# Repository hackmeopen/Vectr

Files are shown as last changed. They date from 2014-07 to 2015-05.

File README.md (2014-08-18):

Vectr
=====

Vectr 3D Sensing Controller

Vectr is an open source 3D sensing controller and sequencer. The board files and firmware are here. Vectr software and hardware are released under 
the Modified BSD License. Vectr uses a number of libraries from Microchip which, although they are free to use,are not fully open source. 
The BSD license allows me to release my contributions as free to use while retaining Microchip's copyrights. This arrangement
was worked out in discussions with the legal department of Microchip.

You are free to use Vectr's firmware and hardware for your own purposes.

Vectr uses Microchip Technology's MGC3130 to sense a user's hand in free space above it's surface. It is able to determine the position of the user's hand within a  cubic volume which is 4inx4inx6in. 

Vectr has 36 LEDs which provide visual feedback about where it senses the user's hand.

It is designed to work with Eurorack modular synthesizers, but the underlying technology can be used for controlling just about anything which will receive an analog voltage input.

Vectr has lots of nifty features for recording sequences of hand movements and playing them back. The sequences can be manipulated as they are played with all sorts of different behaviors. These are the things that make Vectr really special.

So, the code's all there. Vectr uses a PIC32 microcontroller running FreeRTOS. 
There's a lot going on but I've tried to comparmentalize it the best I can. So get started, use it, tweak it, build it!

Cheers

Matt

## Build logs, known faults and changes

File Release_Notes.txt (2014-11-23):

{\rtf1\ansi\ansicpg1252\cocoartf1343\cocoasubrtf160
{\fonttbl\f0\fswiss\fcharset0 Helvetica;}
{\colortbl;\red255\green255\blue255;}
\margl1440\margr1440\vieww10800\viewh8400\viewkind0
\pard\tx720\tx1440\tx2160\tx2880\tx3600\tx4320\tx5040\tx5760\tx6480\tx7200\tx7920\tx8640\pardirnatural

\f0\fs24 \cf0 Vectr Release Notes\
\
Release 1.16 - Fixed a bug in the hold behavior during playback}

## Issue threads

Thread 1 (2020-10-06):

Factory Reset by holding button on power-up

wraybowling, 2020-10-06:
Presently, to factory reset, one has to access the main menu. There seem to be cases where the main menu is inaccessible. It would be best if, when the button is held down on power-up, factory settings are restored. This ensures that any sensor malfunction does not prevent the device from resetting.

See also: https://www.muffwiggler.com/forum/viewtopic.php?f=16&t=99344&p=3362086#p3362086

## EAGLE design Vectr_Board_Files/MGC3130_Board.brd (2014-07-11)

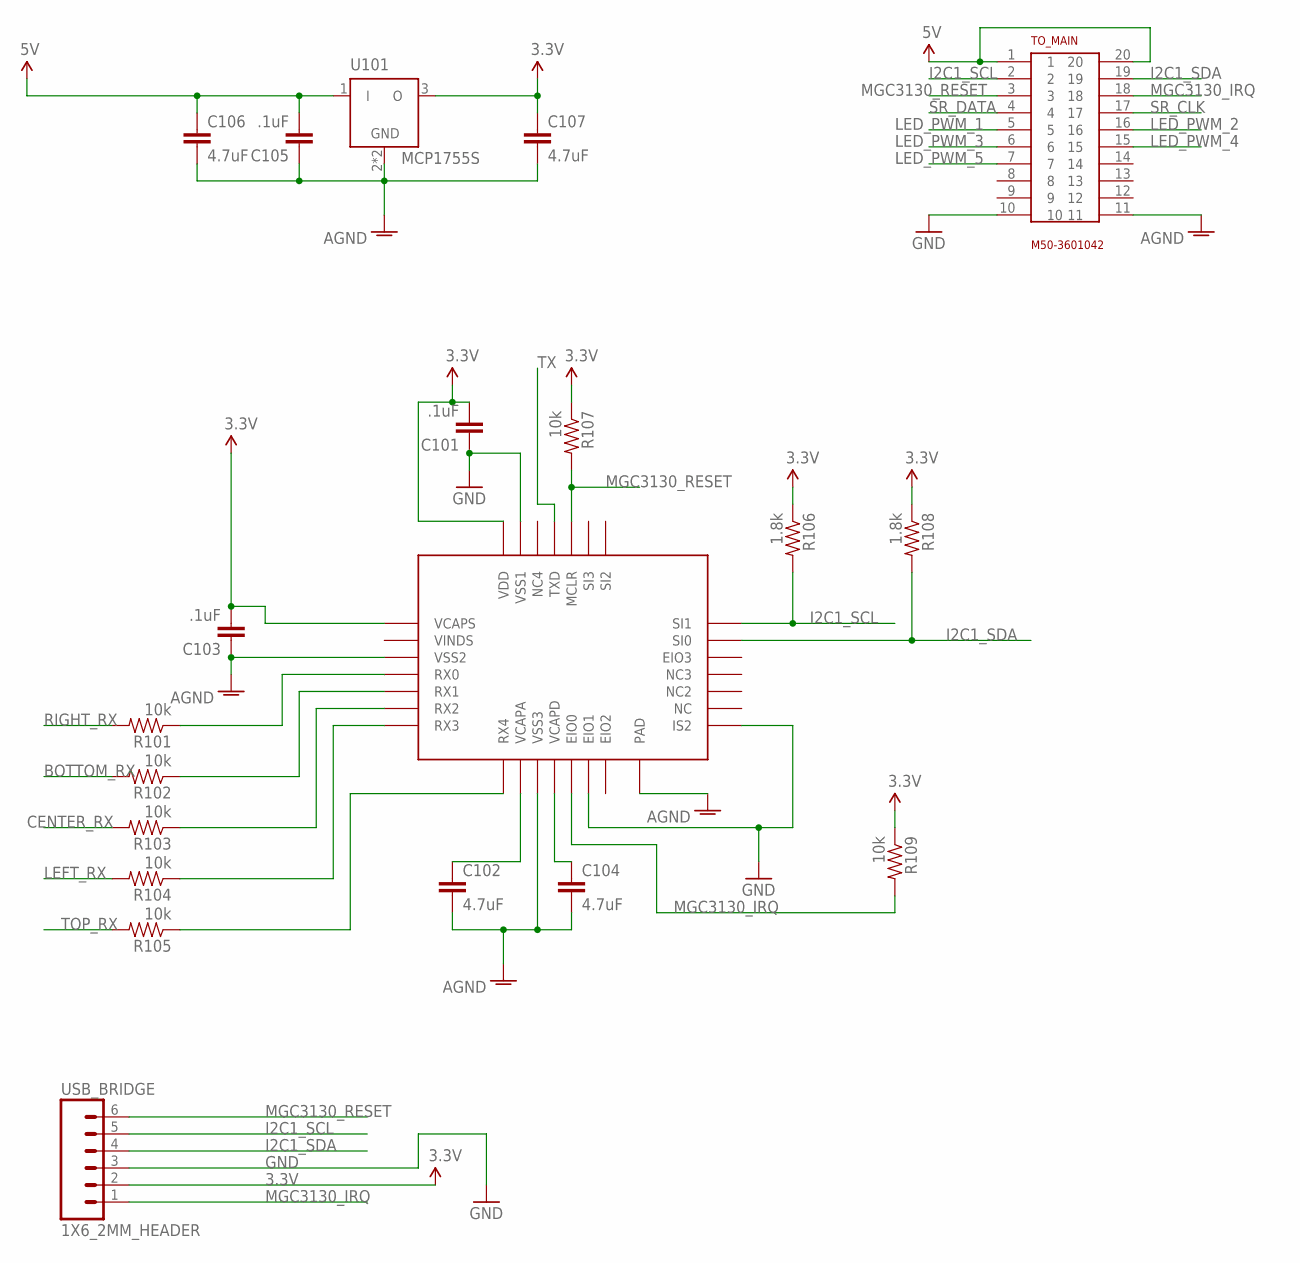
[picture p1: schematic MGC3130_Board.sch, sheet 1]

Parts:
C101, C103, C105: .1uF; 0402-CAP
C102, C104, C106, C107: 4.7uF; 0805
R101, R102, R103, R104, R105, R107, R109: 10k; 0402-RES
R106, R108: 1.8k; 0402-RES
TO_MAIN: M50-3601042
U101: MCP1755S; SOT223
U102: MGC3130; QFN28
USB_BRIDGE: 1X6_2MM_HEADER

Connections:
3.3V: C101.2, C103.2, C107.1, R106.1, R107.1, R108.1, R109.1, U101.3 (O), U102.P$1 (VCAPS), U102.P$28 (VDD), USB_BRIDGE.2
5V: C105.2, C106.1, TO_MAIN.1, TO_MAIN.20, U101.1 (I); also elsewhere on the board
AGND: C102.2, C103.1, C104.2, C105.1, C106.2, C107.2, TO_MAIN.11, U101.2 (GND), U101.4 (GND), U102.P$3 (VSS2), U102.P$10 (VSS3), U102.P$29 (PAD)
BOTTOM_RX: R102.2
CENTER_RX: R103.2
GND: C101.1, TO_MAIN.10, U102.P$13 (EIO1), U102.P$15 (IS2), U102.P$27 (VSS1), USB_BRIDGE.3; also elsewhere on the board
I2C1_SCL: R106.2, TO_MAIN.2, U102.P$21 (SI1), USB_BRIDGE.5
I2C1_SDA: R108.2, TO_MAIN.19, U102.P$20 (SI0), USB_BRIDGE.4
LED_PWM_1: TO_MAIN.5; also elsewhere on the board
LED_PWM_2: TO_MAIN.16; also elsewhere on the board
LED_PWM_3: TO_MAIN.6; also elsewhere on the board
LED_PWM_4: TO_MAIN.15; also elsewhere on the board
LED_PWM_5: TO_MAIN.7; also elsewhere on the board
LEFT_RX: R104.2
MGC3130_IRQ: R109.2, TO_MAIN.18, U102.P$12 (EIO0), USB_BRIDGE.1
MGC3130_RESET: R107.2, TO_MAIN.3, U102.P$24 (MCLR), USB_BRIDGE.6
unnamed: R101.1, U102.P$4 (RX0)
unnamed: R102.1, U102.P$5 (RX1)
unnamed: R103.1, U102.P$6 (RX2)
unnamed: R104.1, U102.P$7 (RX3)
unnamed: R105.1, U102.P$8 (RX4)
unnamed: C102.1, U102.P$9 (VCAPA)
unnamed: C104.1, U102.P$11 (VCAPD)
RIGHT_RX: R101.2
SR_CLK: TO_MAIN.17; also elsewhere on the board
SR_DATA: TO_MAIN.4; also elsewhere on the board
TOP_RX: R105.2
TX: U102.P$25 (TXD)

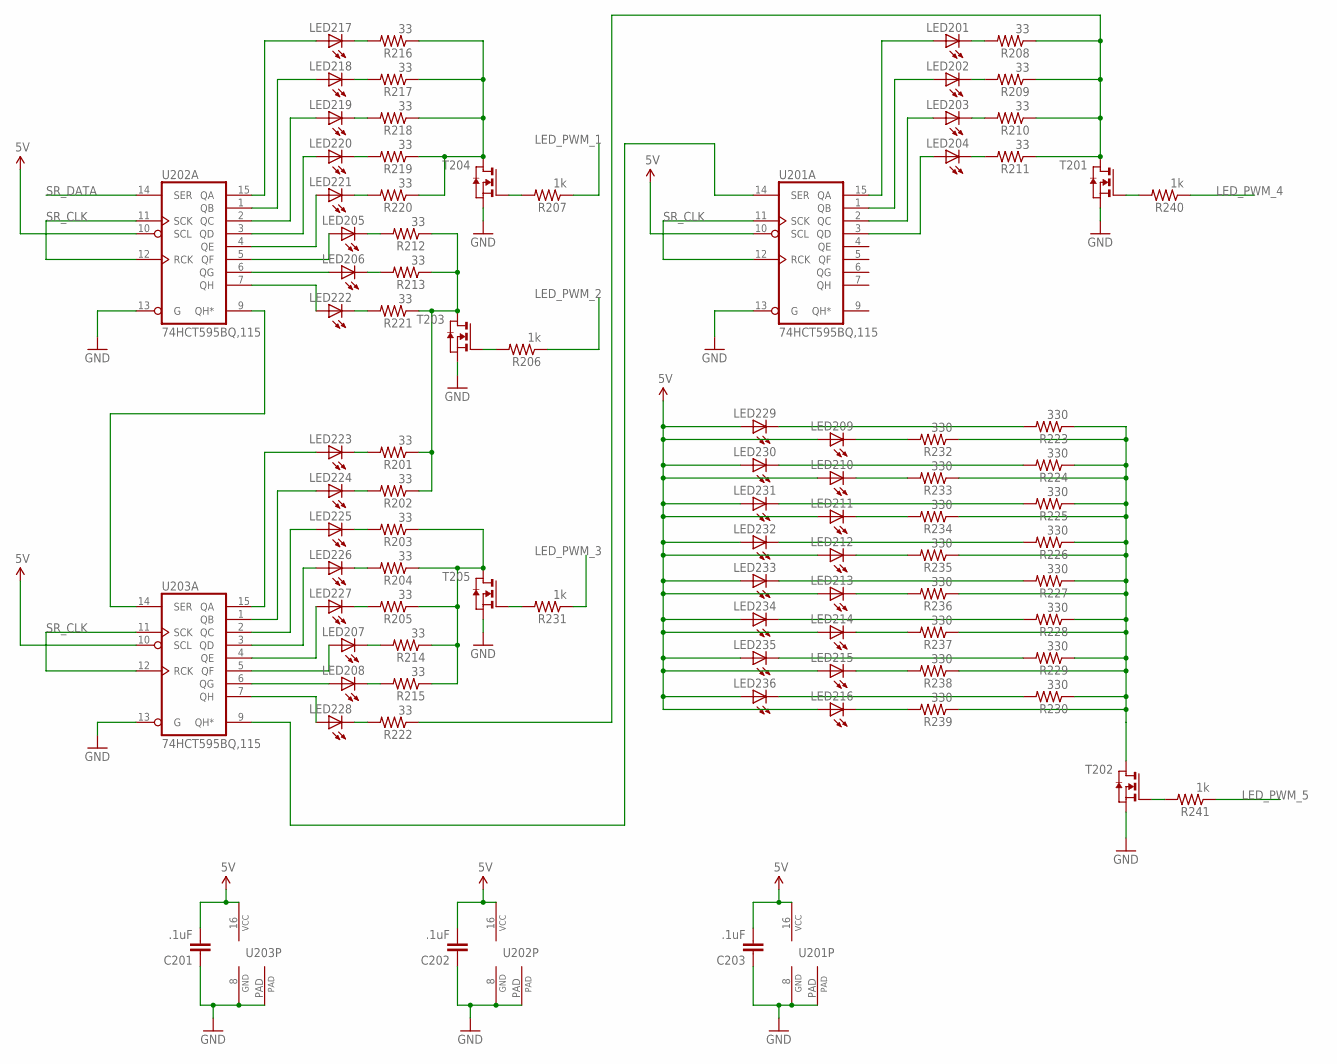
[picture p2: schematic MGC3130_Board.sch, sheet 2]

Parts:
C201, C202, C203: .1uF; 0402-CAP
LED201, LED202, LED203, LED204, LED205, LED206, LED207, LED208, LED217, LED218, LED219, LED220, LED221, LED222, LED223, LED224, LED225, LED226, LED227, LED228: APA3010QBC/D-GX; APA3010
LED209, LED210, LED211, LED212, LED213, LED214, LED215, LED216, LED229, LED230, LED231, LED232, LED233, LED234, LED235, LED236: APA3010SRCPRV-GX; APA3010
R201, R202, R203, R204, R205, R208, R209, R210, R211, R212, R213, R214, R215, R216, R217, R218, R219, R220, R221, R222: 33; 0402-RES
R206, R207, R231, R241: 1k; 0402-RES
R223, R224, R225, R226, R227, R228, R229, R230, R232, R233, R234, R235, R236, R237, R238, R239: 330; 0402-RES
R240: 1k; 0603-RES
T201, T202, T203, T204, T205: NMOSSOT23; SOT-23
U201, U202, U203: 74HCT595BQ,115; DHVQFN16

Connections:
5V: C201.2, C202.2, C203.2, LED209.P$2 (A), LED210.P$2 (A), LED211.P$2 (A), LED212.P$2 (A), LED213.P$2 (A), LED214.P$2 (A), LED215.P$2 (A), LED216.P$2 (A), LED229.P$2 (A), LED230.P$2 (A), LED231.P$2 (A), LED232.P$2 (A), LED233.P$2 (A), LED234.P$2 (A), LED235.P$2 (A), LED236.P$2 (A), U201.10 (SCL), U201.16 (VCC), U202.10 (SCL), U202.16 (VCC), U203.10 (SCL), U203.16 (VCC); also elsewhere on the board
GND: C201.1, C202.1, C203.1, T201.2 (S), T202.2 (S), T203.2 (S), T204.2 (S), T205.2 (S), U201.8 (GND), U201.13 (G), U201.PAD (GND1), U202.8 (GND), U202.13 (G), U202.PAD (GND1), U203.8 (GND), U203.13 (G), U203.PAD (GND1); also elsewhere on the board
LED_PWM_1: R207.1; also elsewhere on the board
LED_PWM_2: R206.1; also elsewhere on the board
LED_PWM_3: R231.1; also elsewhere on the board
LED_PWM_4: R240.1; also elsewhere on the board
LED_PWM_5: R241.1; also elsewhere on the board
unnamed: LED229.P$1 (C), R223.2
unnamed: LED209.P$1 (C), R232.2
unnamed: LED230.P$1 (C), R224.2
unnamed: LED210.P$1 (C), R233.2
unnamed: LED231.P$1 (C), R225.2
unnamed: LED208.P$2 (A), U203.6 (QG)
unnamed: LED211.P$1 (C), R234.2
unnamed: LED232.P$1 (C), R226.2
unnamed: LED212.P$1 (C), R235.2
unnamed: LED234.P$1 (C), R228.2
unnamed: LED233.P$1 (C), R227.2
unnamed: LED213.P$1 (C), R236.2
unnamed: LED214.P$1 (C), R237.2
unnamed: LED235.P$1 (C), R229.2
unnamed: LED215.P$1 (C), R238.2
unnamed: R207.2, T204.3 (G)
unnamed: LED236.P$1 (C), R230.2
unnamed: LED216.P$1 (C), R239.2
unnamed: LED217.P$2 (A), U202.15 (QA)
unnamed: LED218.P$2 (A), U202.1 (QB)
unnamed: LED219.P$2 (A), U202.2 (QC)
unnamed: LED220.P$2 (A), U202.3 (QD)
unnamed: LED221.P$2 (A), U202.4 (QE)
unnamed: LED205.P$2 (A), U202.5 (QF)
unnamed: LED206.P$2 (A), U202.6 (QG)
unnamed: LED222.P$2 (A), U202.7 (QH)
unnamed: LED217.P$1 (C), R216.2
unnamed: LED218.P$1 (C), R217.2
unnamed: LED219.P$1 (C), R218.2
unnamed: LED220.P$1 (C), R219.2
unnamed: LED221.P$1 (C), R220.2
unnamed: LED205.P$1 (C), R212.2
unnamed: LED206.P$1 (C), R213.2
unnamed: LED222.P$1 (C), R221.2
unnamed: R216.1, R217.1, R218.1, R219.1, R220.1, T204.1 (D)
unnamed: R201.1, R202.1, R212.1, R213.1, R221.1, T203.1 (D)
unnamed: LED223.P$2 (A), U203.15 (QA)
unnamed: LED224.P$2 (A), U203.1 (QB)
unnamed: LED225.P$2 (A), U203.2 (QC)
unnamed: LED226.P$2 (A), U203.3 (QD)
unnamed: LED227.P$2 (A), U203.4 (QE)
unnamed: LED207.P$2 (A), U203.5 (QF)
unnamed: LED228.P$2 (A), U203.7 (QH)
unnamed: LED223.P$1 (C), R201.2
unnamed: LED224.P$1 (C), R202.2
unnamed: LED225.P$1 (C), R203.2
unnamed: LED226.P$1 (C), R204.2
unnamed: LED227.P$1 (C), R205.2
unnamed: LED207.P$1 (C), R214.2
unnamed: LED208.P$1 (C), R215.2
unnamed: LED228.P$1 (C), R222.2
unnamed: R203.1, R204.1, R205.1, R214.1, R215.1, T205.1 (D)
unnamed: LED201.P$2 (A), U201.15 (QA)
unnamed: LED202.P$2 (A), U201.1 (QB)
unnamed: LED203.P$2 (A), U201.2 (QC)
unnamed: LED204.P$2 (A), U201.3 (QD)
unnamed: R223.1, R224.1, R225.1, R226.1, R227.1, R228.1, R229.1, R230.1, R232.1, R233.1, R234.1, R235.1, R236.1, R237.1, R238.1, R239.1, T202.1 (D)
unnamed: U202.9 (QH*), U203.14 (SER)
unnamed: LED201.P$1 (C), R208.2
unnamed: LED202.P$1 (C), R209.2
unnamed: LED203.P$1 (C), R210.2
unnamed: LED204.P$1 (C), R211.2
unnamed: R208.1, R209.1, R210.1, R211.1, R222.1, T201.1 (D)
unnamed: U201.14 (SER), U203.9 (QH*)
unnamed: R206.2, T203.3 (G)
unnamed: R231.2, T205.3 (G)
unnamed: R240.2, T201.3 (G)
unnamed: R241.2, T202.3 (G)
SR_CLK: U201.11 (SCK), U201.12 (RCK), U202.11 (SCK), U202.12 (RCK), U203.11 (SCK), U203.12 (RCK); also elsewhere on the board
SR_DATA: U202.14 (SER); also elsewhere on the board

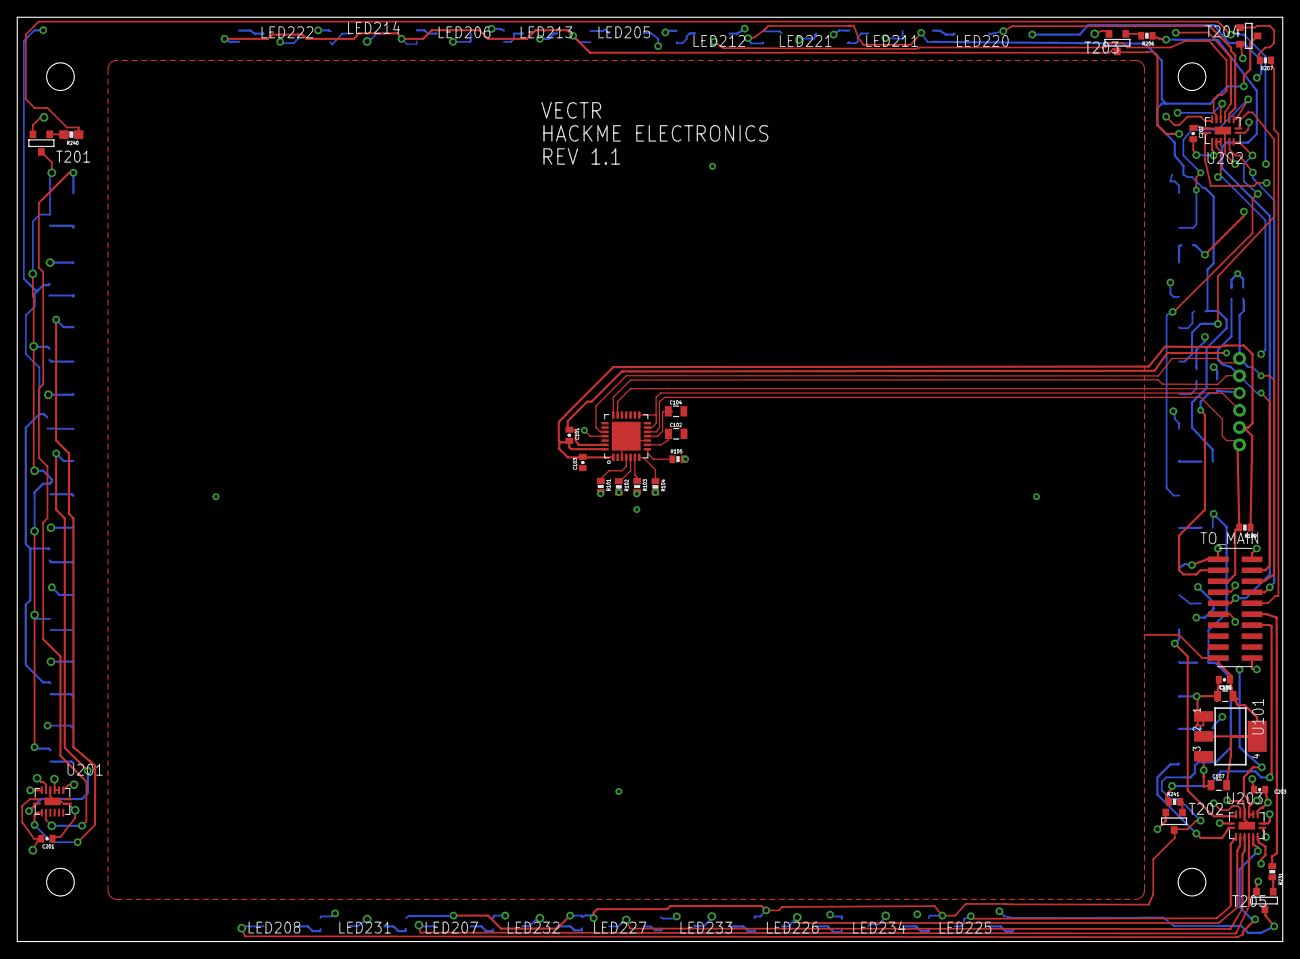
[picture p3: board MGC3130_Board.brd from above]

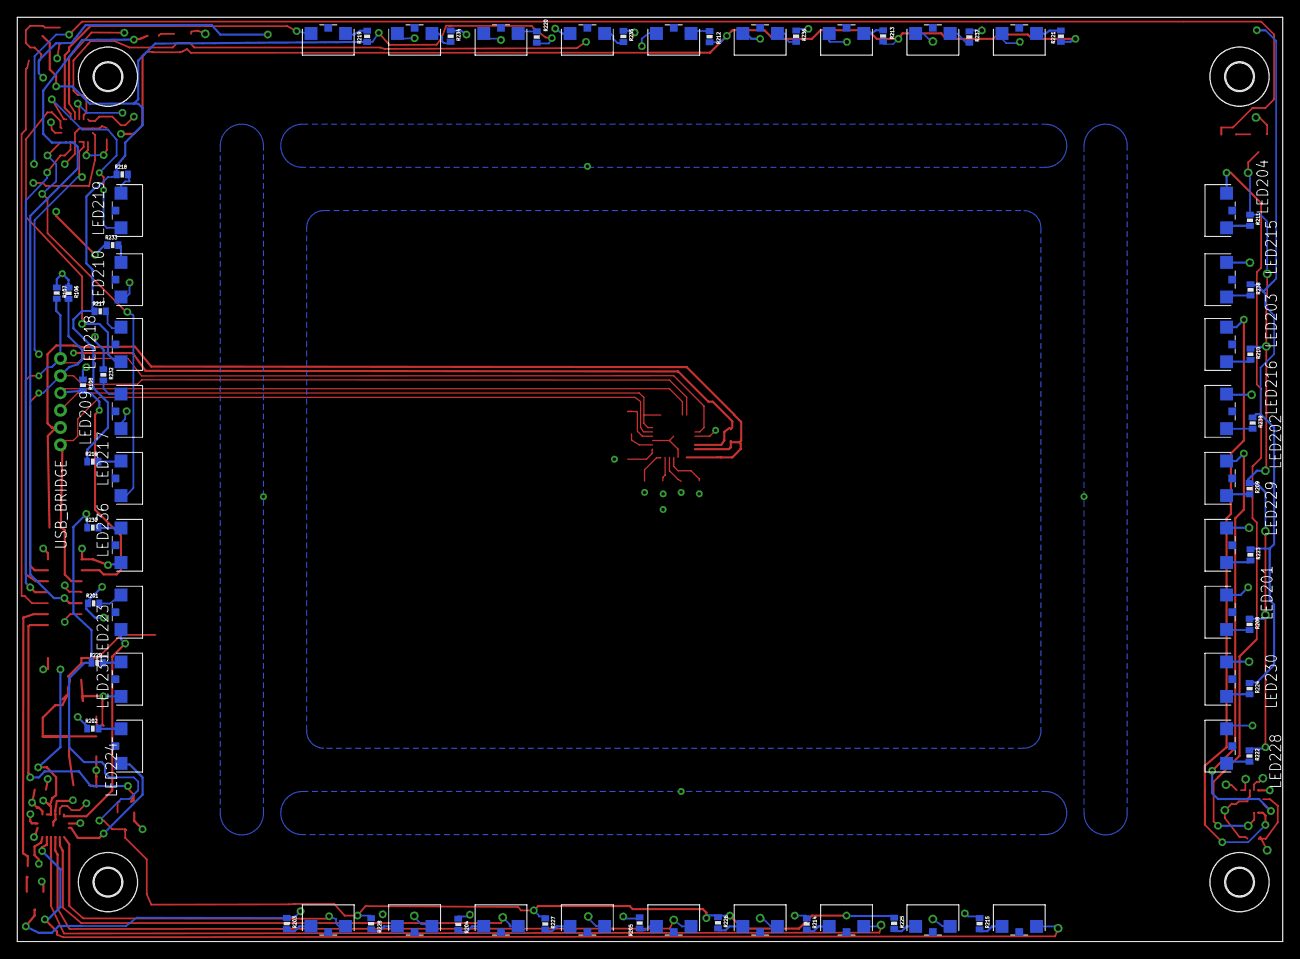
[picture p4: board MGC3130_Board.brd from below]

Board: 4 copper layers, 146.5 x 107.0 mm, 112 parts (81 on the bottom side), 90 nets.

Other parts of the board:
U$1, U$2, U$3, U$4: 3,2

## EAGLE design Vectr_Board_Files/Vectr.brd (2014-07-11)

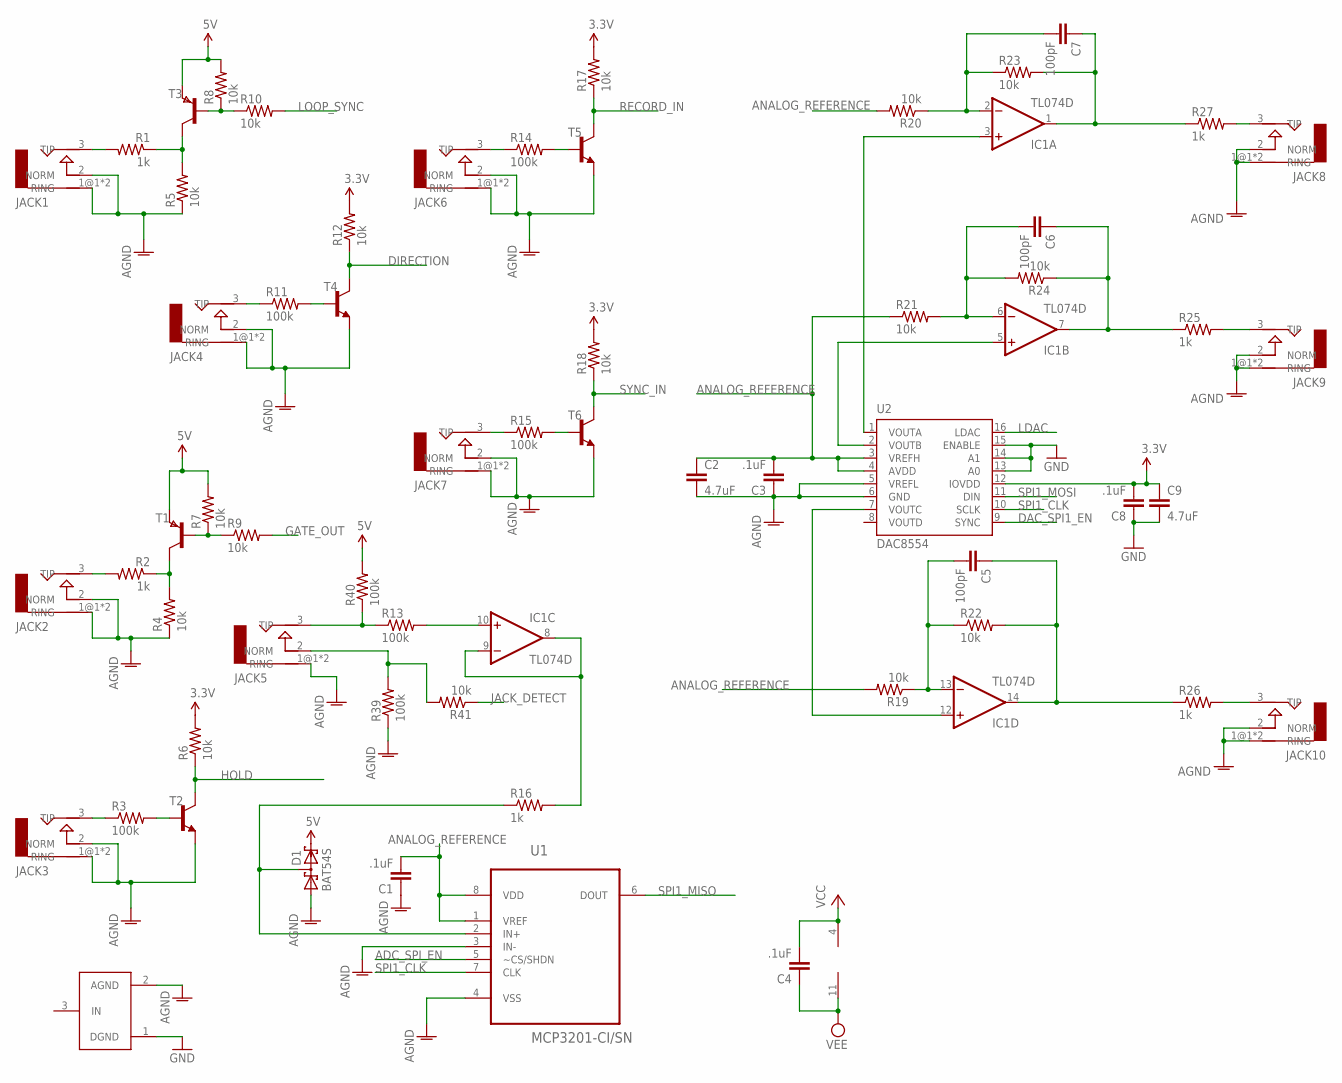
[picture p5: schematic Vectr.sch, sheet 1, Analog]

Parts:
C1, C3, C4, C8: .1uF; 0402-CAP
C2, C9: 4.7uF; 0805
C5, C6, C7: 100pF; 0402-CAP
D1: BAT54S; SOT23
GND_CONNECT: GND_CONNECT
IC1: TL074D; SO14
JACK1, JACK2, JACK3, JACK4, JACK5, JACK6, JACK7, JACK8, JACK9, JACK10: AUDIO-JACKERTHENVAR; ERTHENVAR-JACK
R1, R2, R16, R25, R26, R27: 1k; 0402-RES
R3, R11, R13, R14, R15, R39, R40: 100k; 0402-RES
R4, R5, R6, R7, R8, R9, R10, R12, R17, R18, R19, R20, R21, R22, R23, R24, R41: 10k; 0402-RES
T1, T3: PNPSOT23; SOT-23
T2, T4, T5, T6: TRANSISTOR_NPNSOT23; SOT23
U1: MCP3201-CI/SN; SOIC127P600X175-8N
U2: DAC8554; PW_R-PDSO-G16

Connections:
3.3V: C8.2, C9.1, R6.2, R12.2, R17.2, R18.2, U2.12 (IOVDD); also elsewhere on the board
5V: D1.2 (C2), R7.2, R8.2, R40.2, T1.2 (E), T3.2 (E); also elsewhere on the board
ADC_SPI_EN: U1.5 (~CS/SHDN); also elsewhere on the board
AGND: C1.1, C2.2, C3.1, D1.1 (A1), GND_CONNECT.2 (AGND), JACK1.1@1 (RING), JACK1.1@2 (RING), JACK1.2 (NORM), JACK2.1@1 (RING), JACK2.1@2 (RING), JACK2.2 (NORM), JACK3.1@1 (RING), JACK3.1@2 (RING), JACK3.2 (NORM), JACK4.1@1 (RING), JACK4.1@2 (RING), JACK4.2 (NORM), JACK5.1@1 (RING), JACK5.1@2 (RING), JACK6.1@1 (RING), JACK6.1@2 (RING), JACK6.2 (NORM), JACK7.1@1 (RING), JACK7.1@2 (RING), JACK7.2 (NORM), JACK8.1@1 (RING), JACK8.1@2 (RING), JACK8.2 (NORM), JACK9.1@1 (RING), JACK9.1@2 (RING), JACK9.2 (NORM), JACK10.1@1 (RING), JACK10.1@2 (RING), JACK10.2 (NORM), R4.1, R5.1, R39.1, T2.2 (E), T4.2 (E), T5.2 (E), T6.2 (E), U1.3 (IN-), U1.4 (VSS), U2.5 (VREFL), U2.6 (GND); also elsewhere on the board
ANALOG_REFERENCE: C1.2, C2.1, C3.2, R19.2, R20.2, R21.1, U1.1 (VREF), U1.8 (VDD), U2.3 (VREFH), U2.4 (AVDD); also elsewhere on the board
DAC_SPI1_EN: U2.9 (SYNC); also elsewhere on the board
DIRECTION: R12.1, T4.3 (C); also elsewhere on the board
GATE_OUT: R9.2; also elsewhere on the board
GND: C8.1, C9.2, GND_CONNECT.1 (DGND), U2.13 (A0), U2.14 (A1), U2.15 (ENABLE); also elsewhere on the board
HOLD: R6.1, T2.3 (C); also elsewhere on the board
JACK_DETECT: R41.1; also elsewhere on the board
LDAC: U2.16 (LDAC); also elsewhere on the board
LOOP_SYNC: R10.2; also elsewhere on the board
unnamed: R8.1, R10.1, T3.3 (B)
unnamed: C7.2, IC1.2 (-IN), R20.1, R23.1
unnamed: IC1.10 (+IN), R13.2
unnamed: C7.1, IC1.1 (OUT), R23.2, R27.1
unnamed: R1.1, R5.2, T3.1 (C)
unnamed: JACK1.3 (TIP), R1.2
unnamed: IC1.5 (+IN), U2.2 (VOUTB)
unnamed: JACK4.3 (TIP), R11.1
unnamed: R11.2, T4.1 (B)
unnamed: IC1.8 (OUT), IC1.9 (-IN), R16.2
unnamed: C6.2, IC1.6 (-IN), R21.2, R24.2
unnamed: R7.1, R9.1, T1.3 (B)
unnamed: R2.1, R4.2, T1.1 (C)
unnamed: JACK2.3 (TIP), R2.2
unnamed: C6.1, IC1.7 (OUT), R24.1, R25.1
unnamed: R3.2, T2.1 (B)
unnamed: JACK3.3 (TIP), R3.1
unnamed: C5.2, IC1.13 (-IN), R19.1, R22.1
unnamed: C5.1, IC1.14 (OUT), R22.2, R26.1
unnamed: JACK5.2 (NORM), R39.2, R41.2
unnamed: IC1.3 (+IN), U2.1 (VOUTA)
unnamed: D1.3 (C1A2), R16.1, U1.2 (IN+)
unnamed: JACK8.3 (TIP), R27.2
unnamed: JACK5.3 (TIP), R13.1, R40.1
unnamed: JACK6.3 (TIP), R14.1
unnamed: JACK9.3 (TIP), R25.2
unnamed: R14.2, T5.1 (B)
unnamed: IC1.12 (+IN), U2.7 (VOUTC)
unnamed: JACK10.3 (TIP), R26.2
unnamed: JACK7.3 (TIP), R15.1
unnamed: R15.2, T6.1 (B)
RECORD_IN: R17.1, T5.3 (C); also elsewhere on the board
SPI1_CLK: U1.7 (CLK), U2.10 (SCLK); also elsewhere on the board
SPI1_MISO: U1.6 (DOUT); also elsewhere on the board
SPI1_MOSI: U2.11 (DIN); also elsewhere on the board
SYNC_IN: R18.1, T6.3 (C); also elsewhere on the board
VCC: C4.2, IC1.4 (V+); also elsewhere on the board
VEE: C4.1, IC1.11 (V-); also elsewhere on the board

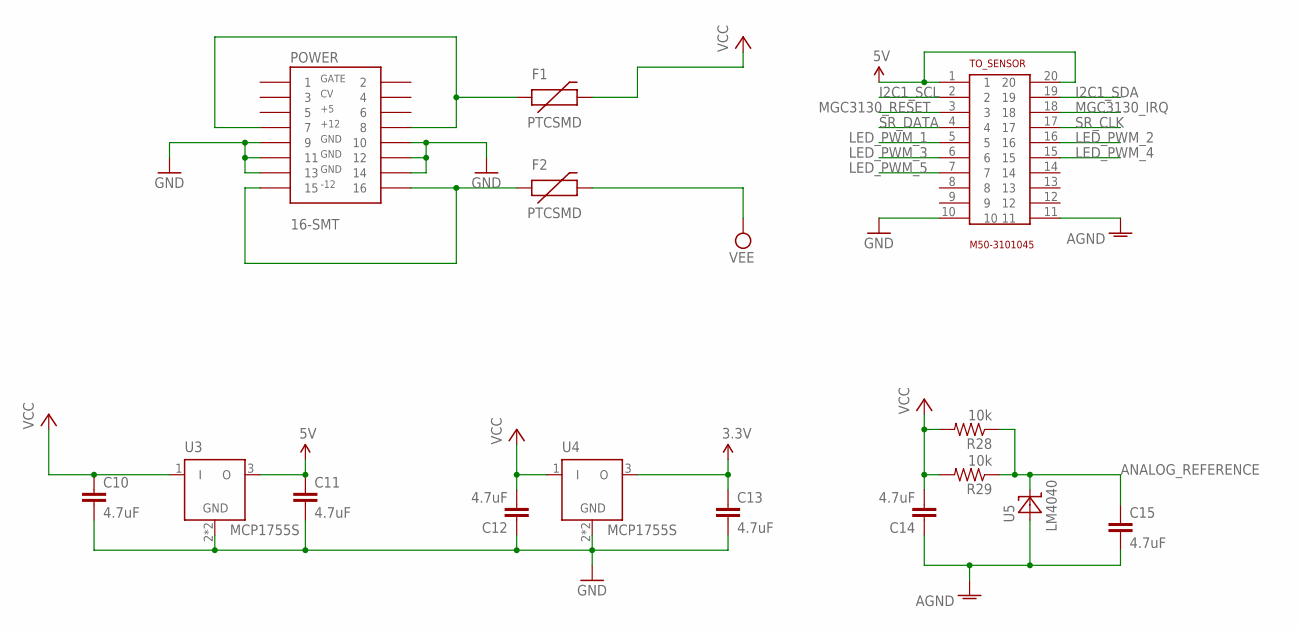
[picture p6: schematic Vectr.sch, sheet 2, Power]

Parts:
C10, C11, C12, C13, C14, C15: 4.7uF; 0805
F1, F2: PTCSMD; PTC-1206
POWER: 16-SMT
R28, R29: 10k; 0402-RES
TO_SENSOR: M50-3101045
U3, U4: MCP1755S; SOT223
U5: LM4040; SOT23

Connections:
3.3V: C13.1, U4.3 (O); also elsewhere on the board
5V: C11.1, TO_SENSOR.1, TO_SENSOR.20, U3.3 (O); also elsewhere on the board
AGND: C14.1, C15.2, TO_SENSOR.11, U5.2 (A); also elsewhere on the board
ANALOG_REFERENCE: C15.1, R28.1, R29.1, U5.3 (C); also elsewhere on the board
GND: C10.2, C11.2, C12.1, C13.2, POWER.P$9 (9), POWER.P$10 (10), POWER.P$11 (11), POWER.P$12 (12), POWER.P$13 (13), POWER.P$14 (14), TO_SENSOR.10, U3.2 (GND), U3.4 (GND), U4.2 (GND), U4.4 (GND); also elsewhere on the board
I2C1_SCL: TO_SENSOR.2; also elsewhere on the board
I2C1_SDA: TO_SENSOR.19; also elsewhere on the board
LED_PWM_1: TO_SENSOR.5; also elsewhere on the board
LED_PWM_2: TO_SENSOR.16; also elsewhere on the board
LED_PWM_3: TO_SENSOR.6; also elsewhere on the board
LED_PWM_4: TO_SENSOR.15; also elsewhere on the board
LED_PWM_5: TO_SENSOR.7; also elsewhere on the board
MGC3130_IRQ: TO_SENSOR.18; also elsewhere on the board
MGC3130_RESET: TO_SENSOR.3; also elsewhere on the board
unnamed: F1.1, POWER.P$7 (7), POWER.P$8 (8)
unnamed: F2.1, POWER.P$15 (15), POWER.P$16 (16)
SR_CLK: TO_SENSOR.17; also elsewhere on the board
SR_DATA: TO_SENSOR.4; also elsewhere on the board
VCC: C10.1, C12.2, C14.2, F1.2, R28.2, R29.2, U3.1 (I), U4.1 (I); also elsewhere on the board
VEE: F2.2; also elsewhere on the board

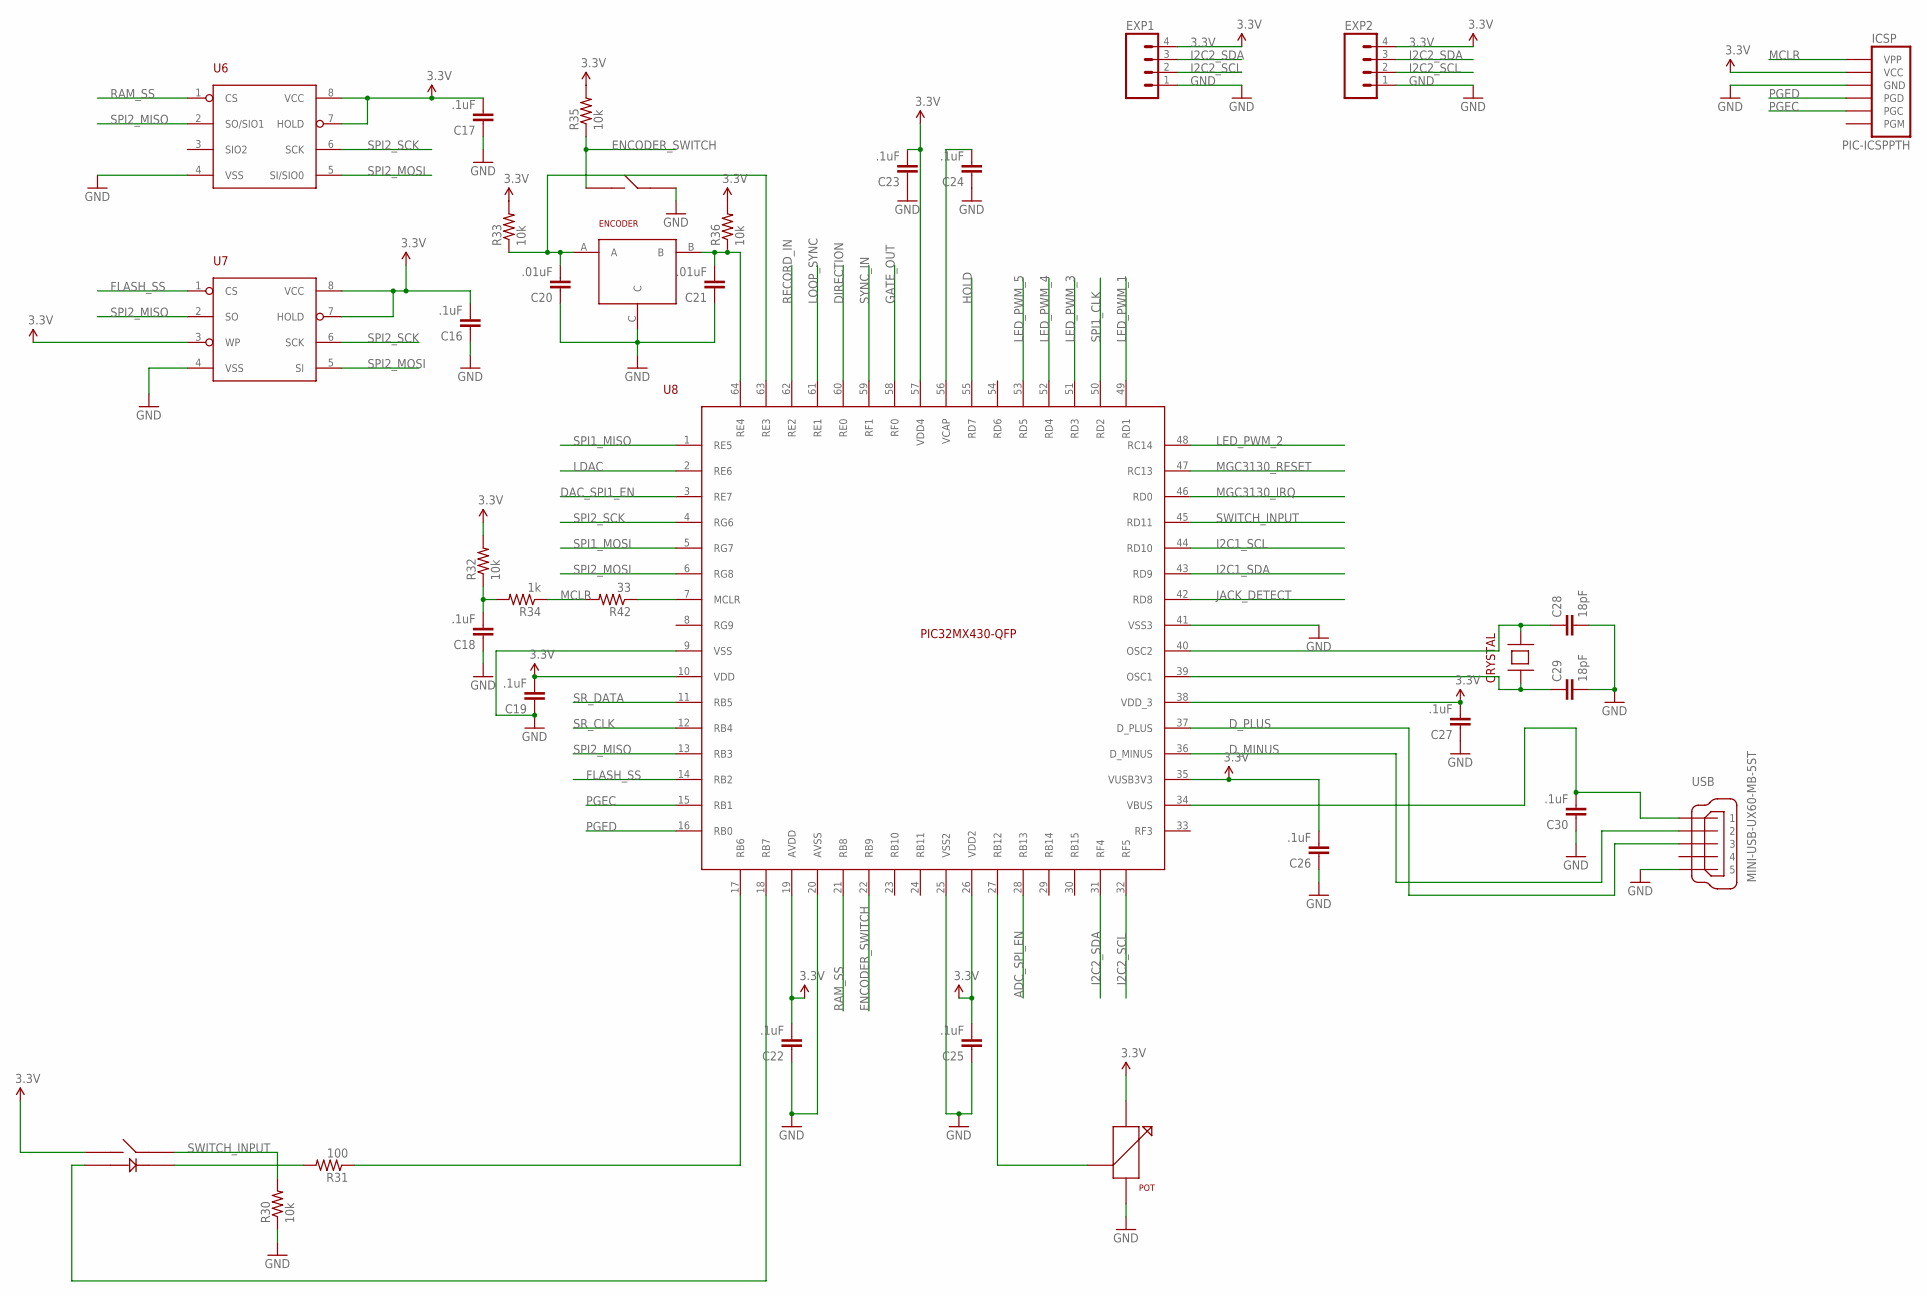
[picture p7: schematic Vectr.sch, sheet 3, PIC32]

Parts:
C16, C17, C18, C19, C22, C23, C24, C25, C26, C27, C30: .1uF; 0402-CAP
C20, C21: .01uF; 0402-CAP
C28, C29: 18pF; 0402-CAP
CRYSTAL: SMD-4-CRYSTAL
ENCODER: PEC16_ENCODER
EXP1, EXP2: M04SMD_STRAIGHT_COMBO; 1X04_SMD_STRAIGHT_COMBO
ICSP: PIC-ICSPPTH; MOLEX-1X6
POT: 9MMPOT
R30, R32, R33, R35, R36: 10k; 0402-RES
R31: 100; 0402-RES
R34: 1k; 0402-RES
R42: 33; 0402-RES
SWITCH: 5GSH9
U6: 23LC512; SO-08
U7: SST25VF010A; SO-08
U8: PIC32MX430-QFP; QFP50P1200X1200X120-64N
USB: MINI-USB-UX60-MB-5ST; UX60-MB-5ST

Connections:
3.3V: C16.2, C17.2, C19.2, C22.2, C23.2, C25.2, C26.2, C27.2, EXP1.4, EXP2.4, ICSP.5 (VCC), POT.1, R32.2, R33.2, R35.2, R36.2, SWITCH.1, U6.7 (HOLD), U6.8 (VCC), U7.3 (WP), U7.7 (HOLD), U7.8 (VCC), U8.10 (VDD), U8.19 (AVDD), U8.26 (VDD2), U8.35 (VUSB3V3), U8.38 (VDD_3), U8.57 (VDD4); also elsewhere on the board
ADC_SPI_EN: U8.28 (RB13); also elsewhere on the board
DAC_SPI1_EN: U8.3 (RE7); also elsewhere on the board
DIRECTION: U8.60 (RE0); also elsewhere on the board
D_MINUS: U8.36 (D_MINUS), USB.2
D_PLUS: U8.37 (D_PLUS), USB.3
ENCODER_SWITCH: ENCODER.D, R35.1, U8.22 (RB9)
FLASH_SS: U7.1 (CS), U8.14 (RB2)
GATE_OUT: U8.58 (RF0); also elsewhere on the board
GND: C16.1, C17.1, C18.1, C19.1, C20.1, C21.1, C22.1, C23.1, C24.1, C25.1, C26.1, C27.1, C28.2, C29.2, C30.1, ENCODER.C, ENCODER.E, EXP1.1, EXP2.1, ICSP.4 (GND), POT.3, R30.1, U6.4 (VSS), U7.4 (VSS), U8.9 (VSS), U8.20 (AVSS), U8.25 (VSS2), U8.41 (VSS3), USB.5; also elsewhere on the board
HOLD: U8.55 (RD7); also elsewhere on the board
I2C1_SCL: U8.44 (RD10); also elsewhere on the board
I2C1_SDA: U8.43 (RD9); also elsewhere on the board
I2C2_SCL: EXP1.2, EXP2.2, U8.32 (RF5)
I2C2_SDA: EXP1.3, EXP2.3, U8.31 (RF4)
JACK_DETECT: U8.42 (RD8); also elsewhere on the board
LDAC: U8.2 (RE6); also elsewhere on the board
LED_PWM_1: U8.49 (RD1); also elsewhere on the board
LED_PWM_2: U8.48 (RC14); also elsewhere on the board
LED_PWM_3: U8.51 (RD3); also elsewhere on the board
LED_PWM_4: U8.52 (RD4); also elsewhere on the board
LED_PWM_5: U8.53 (RD5); also elsewhere on the board
LOOP_SYNC: U8.61 (RE1); also elsewhere on the board
MCLR: ICSP.6 (VPP), R34.1, R42.2
MGC3130_IRQ: U8.46 (RD0); also elsewhere on the board
MGC3130_RESET: U8.47 (RC13); also elsewhere on the board
unnamed: C18.2, R32.1, R34.2
unnamed: C21.2, ENCODER.B, R36.1, U8.64 (RE4)
unnamed: C20.2, ENCODER.A, R33.1, U8.63 (RE3)
unnamed: POT.2, U8.27 (RB12)
unnamed: SWITCH.3, U8.18 (RB7)
unnamed: C28.1, CRYSTAL.3, U8.40 (OSC2)
unnamed: C29.1, CRYSTAL.1, U8.39 (OSC1)
unnamed: C30.2, U8.34 (VBUS), USB.1
unnamed: C24.2, U8.56 (VCAP)
unnamed: R31.2, SWITCH.2
PGEC: ICSP.2 (PGC), U8.15 (RB1)
PGED: ICSP.3 (PGD), U8.16 (RB0)
RAM_SS: U6.1 (CS), U8.21 (RB8)
RECORD_IN: U8.62 (RE2); also elsewhere on the board
RESET: R42.1, U8.7 (MCLR)
SPI1_CLK: U8.50 (RD2); also elsewhere on the board
SPI1_MISO: U8.1 (RE5); also elsewhere on the board
SPI1_MOSI: U8.5 (RG7); also elsewhere on the board
SPI2_MISO: U6.2 (SO/SIO1), U7.2 (SO), U8.13 (RB3)
SPI2_MOSI: U6.5 (SI/SIO0), U7.5 (SI), U8.6 (RG8)
SPI2_SCK: U6.6 (SCK), U7.6 (SCK), U8.4 (RG6)
SR_CLK: U8.12 (RB4); also elsewhere on the board
SR_DATA: U8.11 (RB5); also elsewhere on the board
SWITCH_INPUT: R30.2, SWITCH.4, U8.45 (RD11)
SWITCH_LED1: R31.1, U8.17 (RB6)
SYNC_IN: U8.59 (RF1); also elsewhere on the board

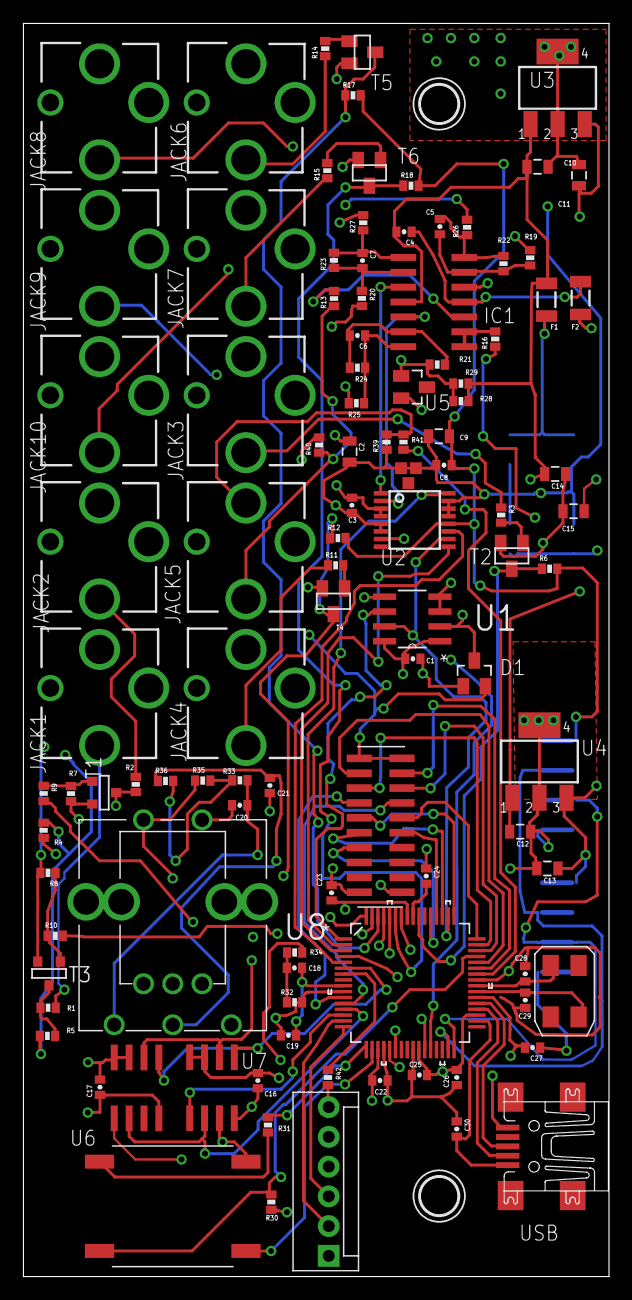
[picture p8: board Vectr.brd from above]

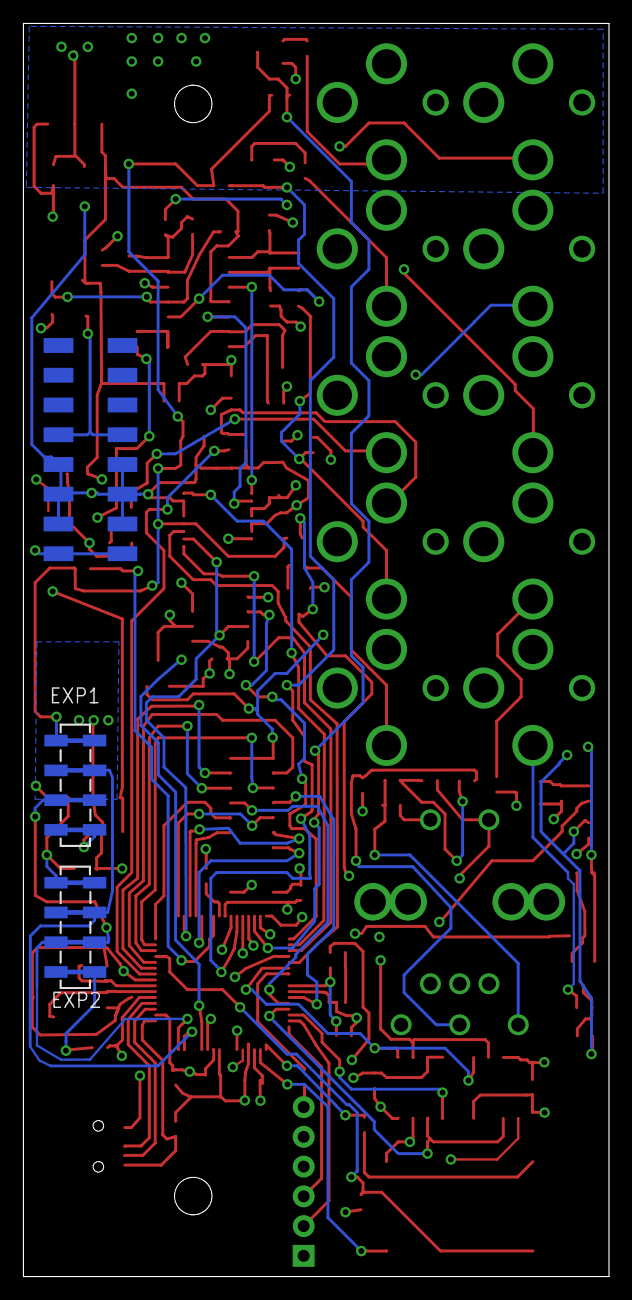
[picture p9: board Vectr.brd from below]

Board: 4 copper layers, 50.0 x 107.0 mm, 111 parts (3 on the bottom side), 90 nets.

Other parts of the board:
U$3, U$5: 3,2

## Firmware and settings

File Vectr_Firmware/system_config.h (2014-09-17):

/*******************************************************************************
  MPLAB Harmony Demo Configuration Header

  Company:
    Microchip Technology Incorporated

  File Name:
    system_config.h

  Summary:
    Top-level configuration header file.

  Description:
    This file contains the configuration settings for the system. It contains
 * the constants for the I/O
*******************************************************************************/

// DOM-IGNORE-BEGIN
/*******************************************************************************
Copyright (c) 2013 released Microchip Technology Inc.  All rights reserved.

Microchip licenses to you the right to use, modify, copy and distribute
Software only when embedded on a Microchip microcontroller or digital signal
controller that is integrated into your product or third party product
(pursuant to the sublicense terms in the accompanying license agreement).

You should refer to the license agreement accompanying this Software for
additional information regarding your rights and obligations.

SOFTWARE AND DOCUMENTATION ARE PROVIDED AS IS WITHOUT WARRANTY OF ANY KIND,
EITHER EXPRESS OR IMPLIED, INCLUDING WITHOUT LIMITATION, ANY WARRANTY OF
MERCHANTABILITY, TITLE, NON-INFRINGEMENT AND FITNESS FOR A PARTICULAR PURPOSE.
IN NO EVENT SHALL MICROCHIP OR ITS LICENSORS BE LIABLE OR OBLIGATED UNDER
CONTRACT, NEGLIGENCE, STRICT LIABILITY, CONTRIBUTION, BREACH OF WARRANTY, OR
OTHER LEGAL EQUITABLE THEORY ANY DIRECT OR INDIRECT DAMAGES OR EXPENSES
INCLUDING BUT NOT LIMITED TO ANY INCIDENTAL, SPECIAL, INDIRECT, PUNITIVE OR
CONSEQUENTIAL DAMAGES, LOST PROFITS OR LOST DATA, COST OF PROCUREMENT OF
SUBSTITUTE GOODS, TECHNOLOGY, SERVICES, OR ANY CLAIMS BY THIRD PARTIES
(INCLUDING BUT NOT LIMITED TO ANY DEFENSE THEREOF), OR OTHER SIMILAR COSTS.
*******************************************************************************/
// DOM-IGNORE-END

#ifndef _SYS_CONFIG_H
#define _SYS_CONFIG_H

#define PLIB_DISABLE_OPTIMIZATION_WARNING 1
#include "peripheral/peripheral.h"


// *****************************************************************************
// *****************************************************************************
// Section: Included Files
// *****************************************************************************
// *****************************************************************************
/*  This section Includes other configuration headers necessary to completely
    define this configuration.
*/

/*System Clock Frequency*/
#define SYS_CLOCK              96000000
#define PERIPHERAL_CLOCK       48000000


/*I2C Definitions*/
/*MGC3130 I2C Definitions*/
#define I2C_MGC3130                 I2C_ID_1
#define I2C_MGC3130_BAUD_RATE       50000
#define I2C_MGC3130_SLAVE_ADDRESS   0x1A

/*MGC3130 Port Definitions*/
#define MGC3130_RESET_PORT          PORT_CHANNEL_C
#define MGC3130_RESET_PIN           PORTS_BIT_POS_13
#define MGC3130_ACTIVATE_RESET      PLIB_PORTS_PinClear(PORTS_ID_0, MGC3130_RESET_PORT,MGC3130_RESET_PIN)
#define MGC3130_CLEAR_RESET         PLIB_PORTS_PinSet(PORTS_ID_0, MGC3130_RESET_PORT,MGC3130_RESET_PIN)

#define MGC3130_TS_PORT     PORT_CHANNEL_D
#define MGC3130_TS_PIN      PORTS_BIT_POS_0
#define MGC3130_TS_PIN_HIGH PLIB_PORTS_PinSet(PORTS_ID_0, MGC3130_TS_PORT,MGC3130_TS_PIN)
#define MGC3130_TS_PIN_LOW  PLIB_PORTS_PinClear(PORTS_ID_0, MGC3130_TS_PORT,MGC3130_TS_PIN)
#define TS_LINE_IS_LOW      !PLIB_PORTS_PinGet(PORTS_ID_0, MGC3130_TS_PORT,MGC3130_TS_PIN)

#define I2C_MGC3130_INT_SOURCE  INT_SOURCE_I2C_1_MASTER
#define ENABLE_I2C_MGC3130_INT  PLIB_INT_SourceEnable(INT_ID_0, I2C_MGC3130_INT_SOURCE)
#define DISABLE_I2C_MGC3130_INT  PLIB_INT_SourceDisable(INT_ID_0, I2C_MGC3130_INT_SOURCE)

#define MGC3130_DATA_READY_INT_SOURCE   INT_SOURCE_EXTERNAL_0
#define ENABLE_MGC3130_DATA_READY_INT   PLIB_INT_SourceEnable(INT_ID_0, MGC3130_DATA_READY_INT_SOURCE)
#define DISABLE_MGC3130_DATA_READY_INT   PLIB_INT_SourceDisable(INT_ID_0, MGC3130_DATA_READY_INT_SOURCE)
#define CLEAR_MGC3130_DATA_READY_INT    PLIB_INT_SourceFlagClear(INT_ID_0, MGC3130_DATA_READY_INT_SOURCE)


//Timers 4 and 5 combine to make a 32 bit timer
#define SAMPLE_TIMER    TMR_ID_4
#define SAMPLE_TIMER_PRESCALE   TMR_PRESCALE_VALUE_1
#define SAMPLE_TIMER_PERIOD     (PERIPHERAL_CLOCK/200)-1 //200Hz
#define SAMPLE_TIMER_INT_SOURCE INT_SOURCE_TIMER_5
#define ENABLE_SAMPLE_TIMER_INT  PLIB_INT_SourceEnable(INT_ID_0, SAMPLE_TIMER_INT_SOURCE)
#define DISABLE_SAMPLE_TIMER_INT PLIB_INT_SourceDisable(INT_ID_0, SAMPLE_TIMER_INT_SOURCE)
#define CLEAR_SAMPLE_TIMER_INT   PLIB_INT_SourceFlagClear(INT_ID_0, SAMPLE_TIMER_INT_SOURCE)
#define SET_SAMPLE_TIMER_PERIOD(newPeriod) PLIB_TMR_Period32BitSet(SAMPLE_TIMER, newPeriod)
#define RESET_SAMPLE_TIMER  PLIB_TMR_Counter32BitClear(SAMPLE_TIMER);

/*SPI Frequency*/
#define SPI_DAC             SPI_ID_1
#define SPI_DAC_BAUD_RATE   1000000 //1.6MHz - Max for the ADC.
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

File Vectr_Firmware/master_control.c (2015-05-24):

#include "system_config.h"
#include "master_control.h"
#include "FreeRTOS.h"
#include "task.h"
#include "semphr.h"
#include "app.h"
#include "mem.h"
#include "i2c.h"
#include "leds.h"
#include "dac.h"
#include "quantization_tables.h"

//TODO: Test - TRIGA menu setting and function.
//TODO: Test - Change the record input - Use the record input to keep synchronized
//TODO: Test - Add the above behaviors to Overdub as well.
//TODO: Test pass through clock.
//TODO: Test hold behaviors in all modes
//TODO: Test - Make the LED blinking indicate sequencing events - clock pulses.
//TODO: Test - the clock stopping control in overdubbing.
//TODO: Test - Make it so an encoder switch press when the record clock is stopped resets the loop.
//TODO: Test - Fix the behavior to go to hold or live playback, simple turns.
//TODO: Test - what happens when multiple switch presses are made during external sync'ed recording
//TODO: Test - Implement automatic speed tracking to playback.
//TODO: Test - Make sure playback is smooth. There may be some sort of jumps.
//TODO: Test - Second press during TRIGA external recording should be disregarded.
//TODO: Test - Implement time quantization - Make a way to turn it on and off with gestures.
//TODO: Test - Fix the switch blinking for when the record mode is internal
//TODO: Test - Make Z output decay to zero when the hand is taken away.
//TODO: Test - Implement the hand gate output "being recorded" - Fake the playback.
//TODO: Test - Add the new clock sync to muting, sequencing.
//TODO: Test - Make playback start back at the beginning when playback is restarted from live play mode.
//TODO: Test - Tap tempo recording starts one clock late.
//TODO: Test - Tap tempo needs to let me keep hitting the switch.
//TODO: Test - Different clock sequence lengths in all modes. especially with the clock sync stuff.
//TODO: Test - Turn off tap tempo when external recording is enabled.
//TODO: Test - Implement quantized speed changes when record is set to external.
//TODO: Test - Deal with all the playback modes with the new clocks.
//TODO: Test - Hand Gate not working in overdub

//TODO: Test - Deal with clock sync during flash playback.
//TODO: Test- Add tap tempo to playback. make it so the clock can keep running and update to new speeds. Maybe during tap tempo the speed averaging the handle clock
// routine doesn't work.
//TODO: Test - Quantized external speed changes not working right. Maybe double the clock
//TODO: Test - Get back to one clock number.
//TODO: Test - Implement clock divisions to do the quantized speed changes. Deal with the clock trigger in external mode?
//TODO: Test - Separate out the LED blinking in playback so it can be called from the timer routine.
//TODO: TEST- Change major to minor in the quantization.
//TODO: Test - Deal with gated modes and clock.
//TODO: Test external clocking with sequencing mode.
//TODO: Test - Handle record clock during air scratching.
//TODO: Test - Check clocks with effects.

//TODO: Initialize the airwheel stuff to neutral.

//TODO: Negative range doesnt go all the way to -5V
//TODO: Figure out what it takes to update the MGC3130 library
//TODO: Specify a solution for microchip demos
//TODO: Make LEDs dim or add screen saver mode when inactive for 5 minutes.


#define MENU_MODE_GESTURE           MGC3130_DOUBLE_TAP_BOTTOM
#define OVERDUB_MODE_GESTURE        MGC3130_DOUBLE_TAP_CENTER
#define MUTE_MODE_GESTURE         MGC3130_DOUBLE_TAP_RIGHT
#define SEQUENCER_MODE_GESTURE      MGC3130_DOUBLE_TAP_LEFT
#define AIR_SCRATCH_MODE_GESTURE    MGC3130_DOUBLE_TAP_TOP

#define X_TOUCH         MGC3130_TOUCH_LEFT
#define Y_TOUCH         MGC3130_TOUCH_TOP
#define Z_TOUCH         MGC3130_TOUCH_RIGHT
#define BOTTOM_TOUCH    MGC3130_TOUCH_BOTTOM
#define CENTER_TOUCH    MGC3130_TOUCH_CENTER

#define GESTURE_DEBOUNCE_TIMER_RESET    100

static VectrDataStruct VectrData;
static VectrDataStruct * p_VectrData;

static uint8_t u8KeyPressFlag = FALSE;//Main switch pressed
static uint8_t u8EncKeyPressFlag = FALSE;//Encoder switch pressed
static uint8_t u8MenuModeFlag = FALSE;
static uint8_t u8TouchFlag = FALSE;
static uint8_t u8SequenceRecordedFlag = FALSE;
static uint8_t u8PlaybackRunFlag = STOP;//Is playback running or not?
static uint8_t u8RecordRunFlag = FALSE;
static uint8_t u8OverdubRunFlag = FALSE;
static uint8_t u8PerformanceModeFlag = NO_PERFORMANCE_ACTIVE;
static uint8_t u8GestureFlag = MGC3130_NO_TOUCH;
static uint8_t u8RecordingArmedFlag = FALSE;
static uint8_t u8PlaybackArmedFlag = FALSE;
static uint8_t u8OverdubArmedFlag = FALSE;
static uint8_t u8LivePlayActivationFlag = FALSE;
static uint8_t u8HandPresentFlag = FALSE;
static uint8_t u8GatePulseFlag = FALSE;
static uint8_t u8ClockPulseFlag = FALSE;
static uint8_t u8PulseExpiredFlag = FALSE;
static uint8_t u8QuantizationGateFlag = FALSE;
static uint8_t u8HandHoldFlag = FALSE;
static uint8_t u8HoldState = OFF;
static uint8_t u8MemCommand;
static uint8_t u8HoldActivationFlag = NO_HOLD_EVENT;
static uint8_t u8SyncTrigger = NO_TRIGGER;
static uint8_t u8SequenceModeChangeSequenceFlag = FALSE;
static uint8_t u16ModulationOnFlag = FALSE;
static uint8_t u8ResetFlag = FALSE;
static uint8_t u8AirScratchRunFlag = FALSE;
static uint8_t u8OperatingMode;
static uint8_t u8PreviousOperatingMode;

static pos_and_gesture_data pos_and_gesture_struct;
static pos_and_gesture_data * p_mem_pos_and_gesture_struct;
static pos_and_gesture_data * p_overdub_pos_and_gesture_struct;
static pos_and_gesture_data hold_position_struct;
static pos_and_gesture_data time_quantize_struct;

static uint8_t u8BufferDataCount = 0;

static memory_data_packet memBuffer;
static memory_data_packet overdubBuffer;

static uint8_t u8SequenceModeIndexes[MAX_NUM_OF_SEQUENCES];
uint8_t u8SequenceModeSelectedSequenceIndex;

static uint8_t u8NumOfClockPulses;
static uint32_t u32NextClockPulseIndex;

static uint16_t u16LastScratchPosition;
static uint16_t u16CurrentScratchSpeedIndex;
static uint32_t u32AirScratchPlaybackSpeed;

static uint8_t u8TapTempoModeActiveFlag;
static uint8_t u8TapTempoKeyPressFlag;
#define LENGTH_OF_TAP_TEMPO_ARRAY   3
static uint32_t u32TapTempoArray[LENGTH_OF_TAP_TEMPO_ARRAY];
static uint8_t u8TapTempoArrayIndex;
static uint8_t u8TapTempoSetFlag;
static uint8_t u8InitTapTempoFlag;
static uint8_t u8ClockTriggerFlag;//Set by the Timer clock routine in app.c TIM3 to inform that the clock expired.

static uint32_t u32NewPlaybackSpeedClocked;
static uint8_t u8NewPlaybackSpeedClockedFlag;
static uint32_t u32NewClockClicks;
static uint8_t u8ExternalAirWheelActiveFlag;
static uint8_t u8ExternalAirWheelActiveSyncFlag;
static uint8_t u8ExternalAirwheelClockDelayCount;
static uint8_t u8ExternalAirwheelClockDelay;
static uint8_t u8ExternalAirwheelExtraClocks;
static uint8_t u8ActivateExternalAirwheelFlag;
static uint8_t u8SkipClockEdge = FALSE;

#define EXTERNAL_AIR_WHEEL_MIN_CHANGE_INCREMENT 32
#define MINIMUM_CLOCK_TICKS 48
#define MAXIMUM_CLOCK_TICKS 16000
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

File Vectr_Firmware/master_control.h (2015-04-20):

/* 
 * File:   master_control.h
 * Author: matthewheins
 *
 * Created on April 27, 2014, 9:01 PM
 */

#ifndef MASTER_CONTROL_H
#define	MASTER_CONTROL_H

enum{
    ENC_SWITCH_PRESSED = 0,
    ENC_SWITCH_RELEASED,
    MAIN_SWITCH_PRESSED,
    MAIN_SWITCH_RELEASED
};

#define NUMBER_OF_OUTPUTS       3
#define MAXIMUM_OUTPUT_VALUE    0xFFFF
#define HALF_OUTPUT_VALUE       0x7FFF
#define ONE_VOLT_OUTPUT_VALUE   0x9996
#define HALF_VOLT_OUTPUT_VALUE  0x8CC4
#define ZERO_VOLT_OUTPUT_VALUE  0x7FFF
#define QUARTER_OUTPUT_VALUE    0x3FFF
#define MIN_OUTPUT_VALUE        0

#define NUM_OF_AXES         3
#define X_OUTPUT_INDEX      0
#define Y_OUTPUT_INDEX      1
#define Z_OUTPUT_INDEX      2
#define CENTER_INDEX        3

#define INITIAL_SPEED_INDEX 511
#define MINIMUM_SPEED_INDEX 0
#define MAXIMUM_SPEED_INDEX 1023


#define NUM_OF_PLAYBACK_SETTINGS    3
enum{
    RECORD = 0,
    PLAY,
    OVERDUB
};

enum{
    SWITCH = 0,
    EXTERNAL
};

enum{
    TRIGGER = 0,
    GATE,
    TRIGGER_AUTO
};

#define NUM_OF_SOURCE_SETTINGS  2
#define NUM_OF_CONTROL_SETTINGS 2

//Setting armed or disarmed states
enum{
    NOT_ARMED = 0,
    ARMED,
    DISARMED
};

/*IO Message Types - These messages are sent by the IO Handler to
 * cause the state of the device to change. They are aggregated on one queue
 * to reduce processing overhead.
 */

typedef struct{
    uint16_t u16messageType;//Which input?
    uint16_t u16message;//What happened?
}io_event_message;

enum{
    RECORD_IN_EVENT = 0,
    PLAYBACK_IN_EVENT,
    HOLD_IN_EVENT,
    SYNC_IN_EVENT,
    JACK_DETECT_IN_EVENT
};

#define GATE_WENT_HIGH  2

enum{
    TRIGGER_WENT_HIGH = 0,
    TRIGGER_WENT_LOW,
    NO_TRIGGER
};

enum{
    NO_HOLD_EVENT = 0,
    HOLD_ACTIVATE,
    HOLD_DEACTIVATE
};

//Track Behavior Modes
#define MAXIMUM_TRACK_BEHAVIOR_INDEX    4
enum{
    HOLD = 0,
    TRACKLIVE,
    LIVE,
    ZERO,
    ENVELOPE_ZERO
};

enum{
    STOP = 0,
    RUN,
    ENDED,
    PAUSED
};

//Playback modes
enum{
    LOOPING = 0,
    PENDULUM,
    FLIP,
    ONESHOT,
    RETRIGGER
};

//Playback directions
enum{
    FORWARD_PLAYBACK = 0,
    REVERSE_PLAYBACK
};

//Gate Modes
enum{
    HAND_GATE = 0,
    RESET_GATE,
    PLAY_GATE,
    RECORD_GATE,
    QUANT_GATE
};

#define MAXIMUM_QUANTIZATION_INDEX  4
//Quantization Modes
enum{
    NO_QUANTIZATION = 0,
    CHROMATIC,
    MAJOR,
    PENTATONIC,
    OCTAVE
};

//Modulation modes.
enum{
    SPEED = 0,
    QUANTIZED_SPEED,
    SCRUB,
    TRIM,
    MIRROR
};

//Memory definitions
#define NUM_OF_DATA_ITEMS_FOR_BUFFER    2

enum{
    READ_RAM = 0,
    WRITE_RAM,
    WRITETHENREAD_RAM,
    READ_FLASH_FILE_TABLE,
    WRITE_FLASH_FILE_TABLE,

};

//Sequence Mode
#define MAX_NUM_OF_SEQUENCES    4
#define NO_SEQUENCE_MASK    0xFF
#define RAM_SEQUENCE_MASK   0xFE

/*Sequence States - These are */
enum{
    NO_SEQUENCE_STORED = 0,
    SEQUENCE_STORED,
    SEQUENCE_SELECTED
};

#define MAX_NUM_OF_CLOCK_PULSES 16
#define CLOCK_PULSE_COUNT_INCREMENT 6

//Number of clock pulse settings
enum{
    CLOCK_PULSE_1 = 0,
    CLOCK_PULSE_2,
    CLOCK_PULSE_4,
    CLOCK_PULSE_8,
    CLOCK_PULSE_16
};

/*Air Scratch constants*/
#define SCRATCH_SLOWDOWN_CONSTANT   10
#define SCRATCH_SPEEDUP_CONSTANT    10

/*Quantization*/
//1 VOLT PER OCTAVE = .083333V/NOTE
//16 BIT = 65535 STEPS FOR 10 VOLTS = 120 NOTES
//1 NOTE = 546.133 STEPS PER NOTE
#define CHROMATIC_NOTE_SPACING


#define MIN_SLEW_RATE   0
#define MID_SLEW_RATE   2048
#define MAX_SLEW_RATE   4096
#define SLEW_RATE_LED_INCREMENT 1024
#define SLEW_RATE_INCREMENT 32
#define SLEW_RATE_LED_SCALING   1

#define LINEARITY_MIN       0   //Pure log
#define LINEARITY_STRAIGHT  64  //Linear
#define LINEARITY_MAX       127 //Pure antilog
#define LINEARITY_LED_INCREMENT 32
#define BIT_LENGTH_OF_LINEARITY_STRAIGHT    6
#define LINEARITY_LED_SCALING   16 //MAX BRIGHTNESS divided by the size of
/*Record, Playback, and Overdub all have */

#define MAXIMUM_RANGE_INDEX 4
enum{
    RANGE_BI_5V = 0,
    RANGE_BI_2_5V,
    RANGE_UNI_5V,
    RANGE_UNI_1V,
    RAMP
};

//Operating Modes
enum{
    LIVE_PLAY=0,
    RECORDING,
    PLAYBACK,
    OVERDUBBING,
    SEQUENCING,
    MUTING,
    AIR_SCRATCHING
};

//Performance Modes
enum{
    NO_PERFORMANCE_ACTIVE = 0,
    MENU_MODE,
    OVERDUB_MODE,
    MUTE_MODE,
    SEQUENCER_MODE,
    AIR_SCRATCH_MODE
};

#define DEFAULT_SETTINGS_TIME_LENGTH    30000

typedef struct{
    uint8_t u8Range[NUMBER_OF_OUTPUTS];//Keep this as the first entry...things could get messed up.
    uint16_t u16CurrentXPosition;
    uint16_t u16CurrentYPosition;
    uint16_t u16CurrentZPosition;
    uint16_t u16SlewRate[NUMBER_OF_OUTPUTS];
    uint16_t u16Linearity[NUMBER_OF_OUTPUTS];
    uint8_t u8Source[NUM_OF_PLAYBACK_SETTINGS];
    uint8_t u8Control[NUM_OF_PLAYBACK_SETTINGS];
    uint8_t u8PlaybackMode;//Looping or whatnot
    uint8_t u8PlaybackDirection;//forward or reverse
    uint8_t u8ModulationMode;//Speed or Scrub
    uint8_t u8HoldBehavior[NUMBER_OF_OUTPUTS];//Hold the outputs
    uint8_t u8OverdubStatus[NUMBER_OF_OUTPUTS];
    uint8_t u16Quantization[NUMBER_OF_OUTPUTS];
    uint8_t u8MuteState[NUMBER_OF_OUTPUTS];
    uint8_t u8NumClocks;//The number of clocks coming and going.
    uint8_t u8GateMode;
    uint8_t u8TimeQuantization[NUMBER_OF_OUTPUTS];
}VectrDataStruct;
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

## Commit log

2014-01-20 First Real Commit
    [MGC3130_Board.brd, MGC3130_Board.sch, Vectr.brd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]
2014-07-11 These are the final files for the first Vectr production run.
    [MGC3130_Board.brd, MGC3130_Board.sch, Vectr.brd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]
2014-07-11 Delete MGC3130_Board.brd
    Reorganizing file structure
    [MGC3130_Board.brd]
2014-07-11 Delete MGC3130_Board.sch
    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
    [MGC3130_Board.sch]
2014-07-11 Delete Vectr.brd
    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
    [Vectr.brd]
2014-07-11 Delete Vectr.sch
    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
    [Vectr.sch]
2014-07-11 Delete Vectr_Combined.brd
    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
    [Vectr_Combined.brd]
2014-07-11 Fixing bugs. Added a variable for the start of sequence to ease effects developement
    [master_control.c, mem.c]
2014-07-22 Fixed bug in writing to flash file table
    [master_control.c, mem.c]
2014-07-23 Fixed bugs in recording and getting playback to start after storing a sequence
    [app.c, leds.c, master_control.c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]
2014-07-24 Fixed a bug in the flash storage of sequences. Writing to flash requires min of 20us.
    [master_control.c, mem.c, menu.c]
2014-07-24 Fixing bug because the last 4 bytes of a flash sector are not used because the packet size is 12 bytes
    [mem.c, mem.h]
2014-07-24 Correcting some clock generation logic
    [master_control.c]
2014-07-25 Fixed the length of flash storage and flash playback, revised the hold modes, made it possible to adjust hold modes
    [master_control.c, mem.c]
2014-07-28 Range fixes, slew fixes, implemented gates, problem with clock output to be resolved
    [app.c, app.h, leds.c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]
2014-07-28 Developed new clock algorithm with Timer 3
2014-07-31 Null checking to find a bug.
    [MGC3130_Board.brd]
2014-08-04 Lots of bug fixes. Modulations working.
    [app.c, leds.c, master_control.c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]
2014-08-06 Added a switch LED mode for blinking red and green to indicate air scratch mode
2014-08-12 Bug fixing in overdub and effects. Still a bug in scrub
    [master_control.c, mem.c, mem.h]
2014-08-13 Fixed a bug in the scrub code
    [app.c, master_control.c, mem.c]
2014-09-05 Beginning revision to board files
    [Vectr_1_3.brd, Vectr_1_3.sch]
2014-09-07 Working out some bugs
    [app.h, dac.c, leds.c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]
2014-09-09 Fixed bugs in the hold mode and clock generation
    [master_control.c, menu.c]
2014-09-10 Working on quantization bug
    [quantization_tables.h]
2014-09-16 Working on bugs with gated playback
    [master_control.c, master_control.h]
2014-09-17 Fixed bugs in triggering
    [leds.c, master_control.c, system_config.h]
2014-09-23 Improving LED feedback
2014-09-23 Correcting a bug in the gated overdub. Adding a behavior for the red LEDs to illuminate when no axis is selected in overdub or mute mode.
    [leds.c, master_control.c]
2014-09-26 Fixing a bug in the record triggering
    [master_control.c]
2014-09-27 Fixed LED behavior in Record and on exit from Overdub
    [app.c, master_control.c]
2014-10-26 Fixed a recording bug where hold would be accidentally triggered
    [master_control.c]
2014-11-23 Fixed a bug in the hold behavior during playback
    [master_control.c]
2014-12-30 Interim Board Update
    [Vectr_1_3.brd, Vectr_1_3.sch]
2014-12-31 Changing connectors
    [MGC3130_Board.brd, MGC3130_Board.sch, Vectr_1_3.brd]
2015-01-04 Preliminary Final Revision
    [MGC3130_Board.brd, Vectr.brd, Vectr.sch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]
2015-01-05 Interim update. Investigating overdub bug
    [master_control.c]
2015-02-03 Working input clock counting, starting switch blink modifications
2015-02-05 More input clock counting, now syncing the switch LED
2015-02-13 Adding the loop reset when playback is paused
    [master_control.c, menu.c]
2015-02-20 Fixed up tap tempo all the way to the point of recording and changing playback speed.
    [leds.h, master_control.c]
2015-02-25 Fixed the double clock handling during playback
    [master_control.c]
2015-03-03 Code taken to the synth meet. Still bugs left.
    [leds.c, master_control.c, master_control.h]
2015-03-03 Removed a few bugs in playback
    [master_control.c, master_control.h]
2015-03-06 Getting the external tempo changes fixed up.
    [app.c, master_control.c, master_control.h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]
2015-03-06 Moving the switch LED blinking out from clock routine
2015-03-09 Separating out led blinking and playback clock
2015-03-10 External synced airwheel not working so hot
    [app.c, master_control.c]
2015-03-14 Airwheel external clock running, still some bugs
    [app.c, master_control.c]
2015-03-17 Fixed up quantized speed control. Overdub switch LED blinking.
    [app.c, app.h, master_control.c]
2015-03-25 Fixed a live play activation bug in Overdubbing
    [app.c, master_control.c, menu.c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]
2015-04-03 Fixed the clock sync bug
    [app.c, master_control.c]
2015-04-06 No known bugs. Fixed recording and overdubbing
    [master_control.c, master_control.h, mem.c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]
2015-04-23 Fixed a time quantization bug when the device was slowed down
    [master_control.c]
2015-04-27 Fixed a bug with conflict between tap tempo while an external clock is running.
    [master_control.c]
2015-05-01 Fixed a tap tempo bug
    [master_control.c]
2015-05-22 Looking into an overdubbing bug
    [app.c, dac.c, leds.c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]
2015-05-24 Fixed a bug in the overdubbing
    [leds.c, master_control.c, mem.c]
2016-01-27 Correcting the board files to match original production Vectr
    [MGC3130_Board.brd, MGC3130_Board.sch, Vectr_1_3.brd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]

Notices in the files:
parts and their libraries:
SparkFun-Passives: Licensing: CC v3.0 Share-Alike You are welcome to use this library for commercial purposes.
